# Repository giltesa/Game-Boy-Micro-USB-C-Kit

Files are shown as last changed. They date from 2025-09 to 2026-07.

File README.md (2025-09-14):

# Game Boy Micro: USB-C Kit

The <strong>Game Boy Micro: USB-C</strong> is a board that allows you to replace the original charging connector with a modern and standard <strong>USB-C</strong> port.

<strong>If your original connector is too old or damaged</strong> and you need a new one, or <strong>if you would like to charge your Game Boy Micro with a standard USB-C charger</strong>, like the charger for your <strong>Nintendo Switch</strong>, phone, or laptop, you can do so with this board.

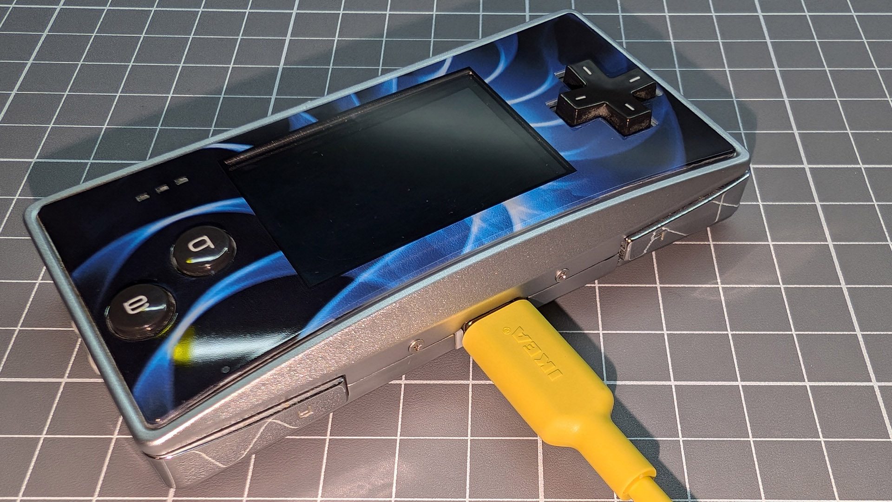
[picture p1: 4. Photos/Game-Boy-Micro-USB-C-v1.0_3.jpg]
GAME-BOY-MICRO-USB-C-Kit

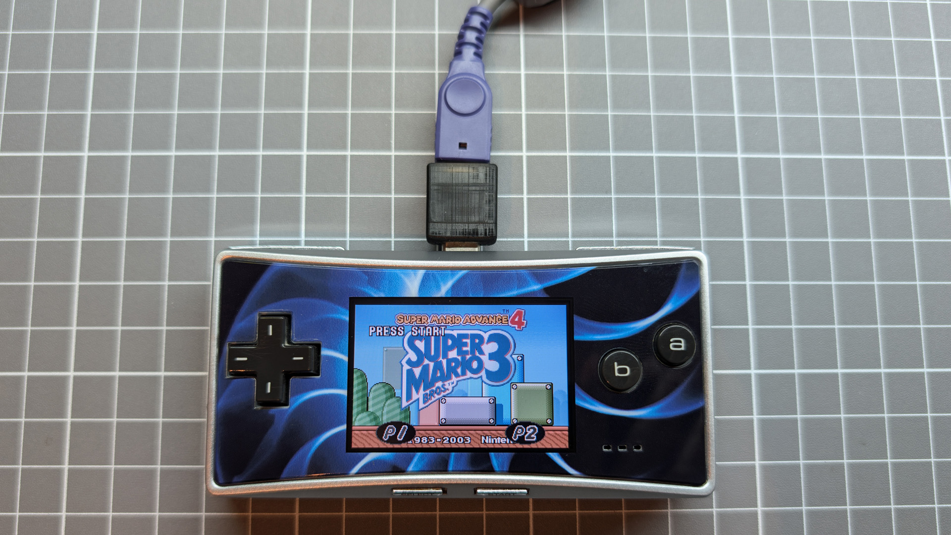
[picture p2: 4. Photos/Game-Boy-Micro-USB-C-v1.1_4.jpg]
GAME-BOY-MICRO-USB-C-Kit


## Would you like it?

[**Game Boy Micro: USB-C Kit**](https://shop.giltesa.com/product/game-boy-micro-usb-c-kit/)

## License

This project is licensed under a **Creative Commons** license:
**[Attribution-NonCommercial-ShareAlike 4.0 International (CC BY-NC-SA 4.0) ](https://creativecommons.org/licenses/by-nc-sa/4.0/)**

Check the [LICENSE.md](LICENSE.md) for more information.

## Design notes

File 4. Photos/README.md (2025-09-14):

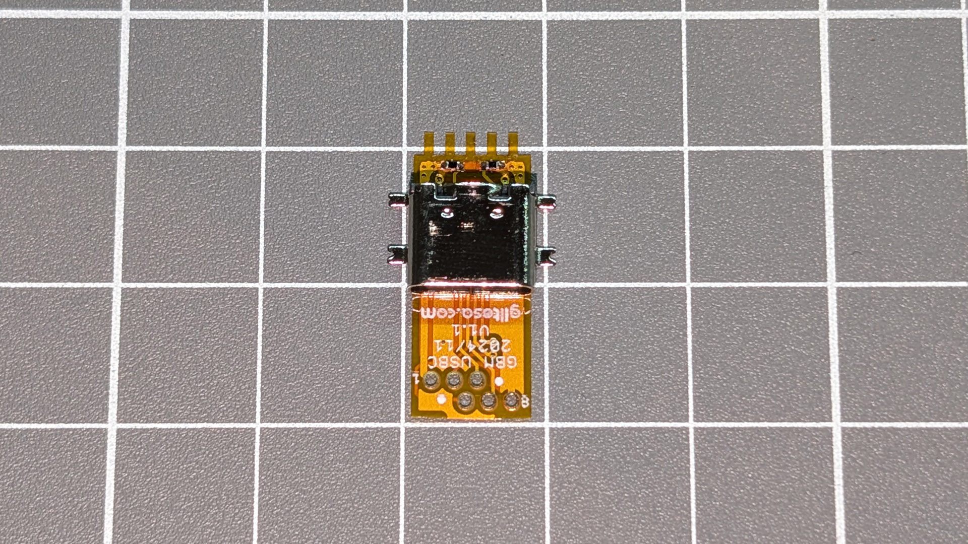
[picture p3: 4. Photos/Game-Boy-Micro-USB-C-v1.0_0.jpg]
GAME-BOY-MICRO-USB-C-Kit

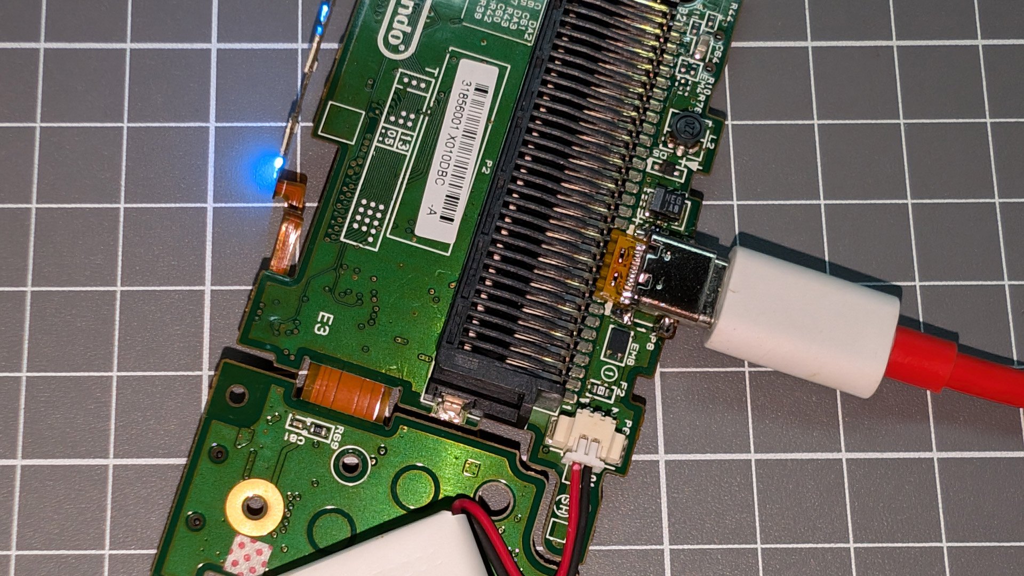
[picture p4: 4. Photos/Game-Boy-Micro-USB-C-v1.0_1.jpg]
GAME-BOY-MICRO-USB-C-Kit

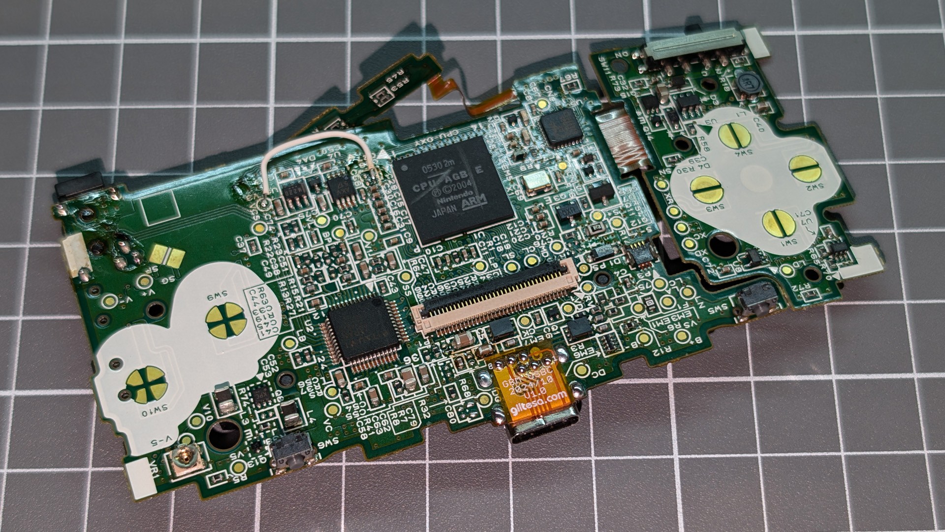
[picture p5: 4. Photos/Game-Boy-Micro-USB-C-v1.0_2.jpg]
GAME-BOY-MICRO-USB-C-Kit

GAME-BOY-MICRO-USB-C-Kit
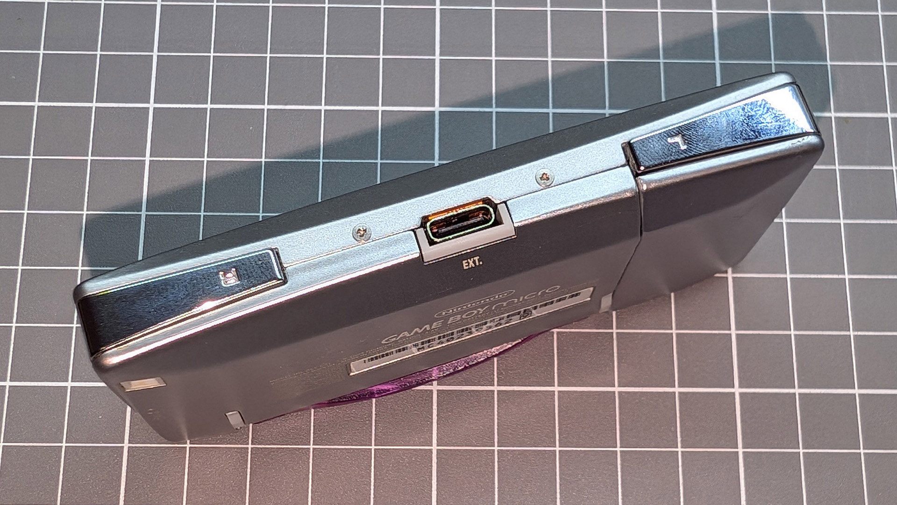
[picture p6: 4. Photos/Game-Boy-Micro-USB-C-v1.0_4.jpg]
GAME-BOY-MICRO-USB-C-Kit


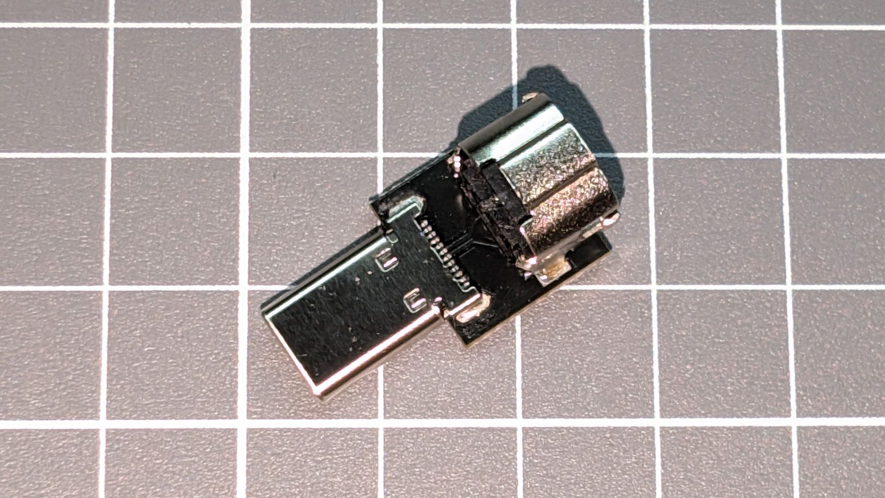
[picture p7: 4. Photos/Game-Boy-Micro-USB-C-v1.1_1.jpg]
GAME-BOY-MICRO-USB-C-Kit

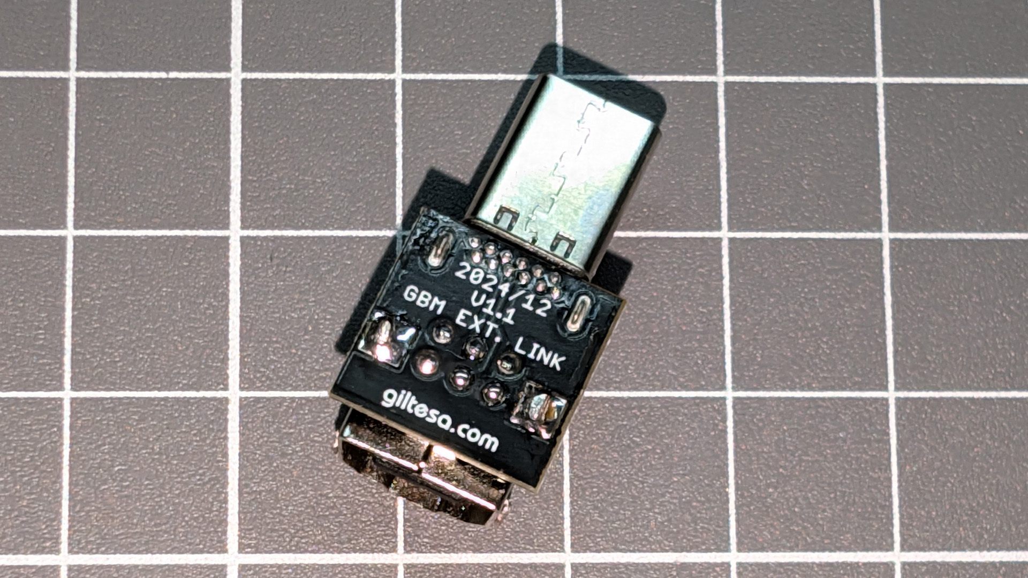
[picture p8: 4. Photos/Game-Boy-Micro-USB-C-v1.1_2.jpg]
GAME-BOY-MICRO-USB-C-Kit

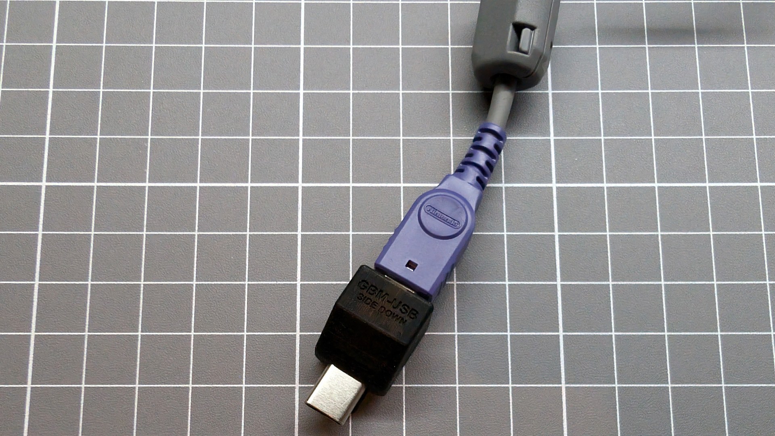
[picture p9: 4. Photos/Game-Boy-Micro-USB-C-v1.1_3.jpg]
GAME-BOY-MICRO-USB-C-Kit

GAME-BOY-MICRO-USB-C-Kit

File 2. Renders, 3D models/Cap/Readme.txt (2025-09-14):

The plastic cap is too weak and would have been a single color. In the end, I scrapped the idea, which is why it’s not included.

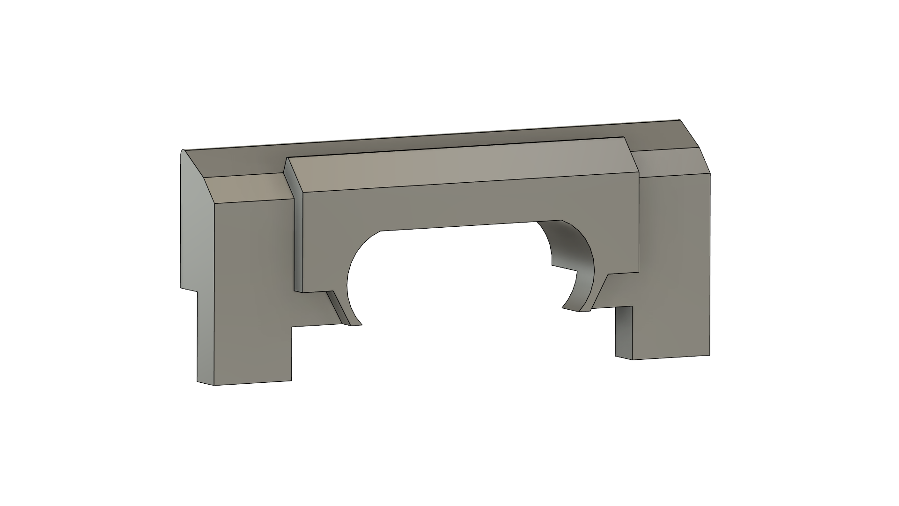
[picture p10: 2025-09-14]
2. Renders, 3D models/Cap/GBM v13.png

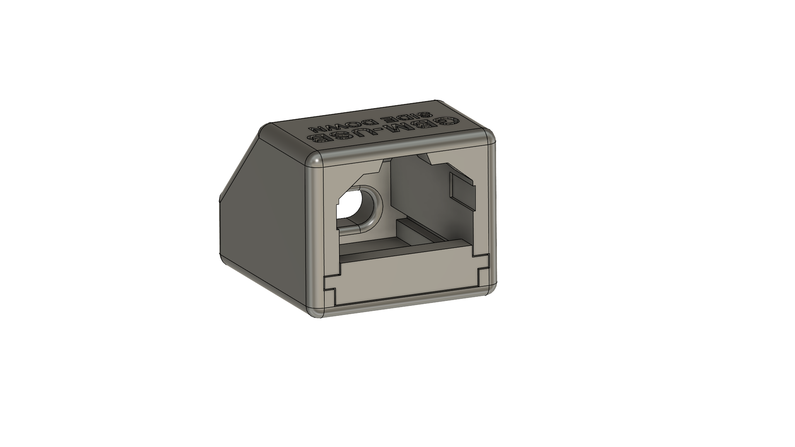
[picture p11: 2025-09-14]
2. Renders, 3D models/Adapter/GBM-ADAPTER_v33.png

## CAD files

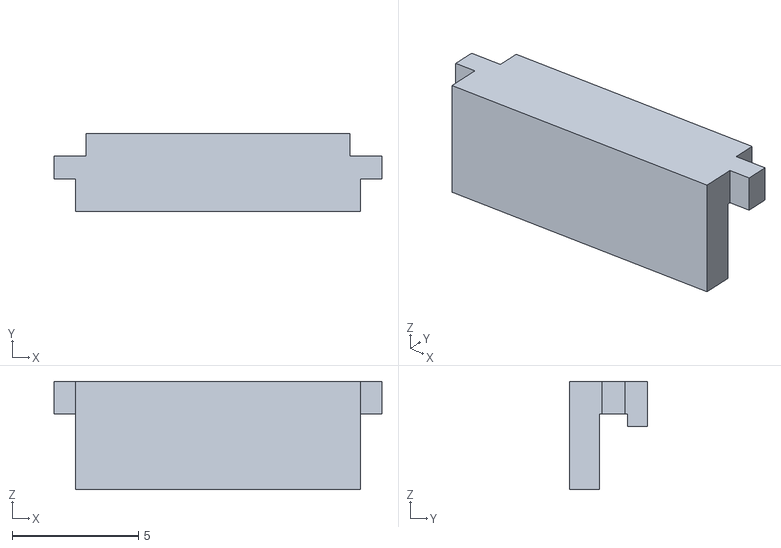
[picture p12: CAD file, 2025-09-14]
2. Renders, 3D models/Adapter/GBM-ADAPTER_LID_v33.stl
13.0 x 3.10 x 4.30

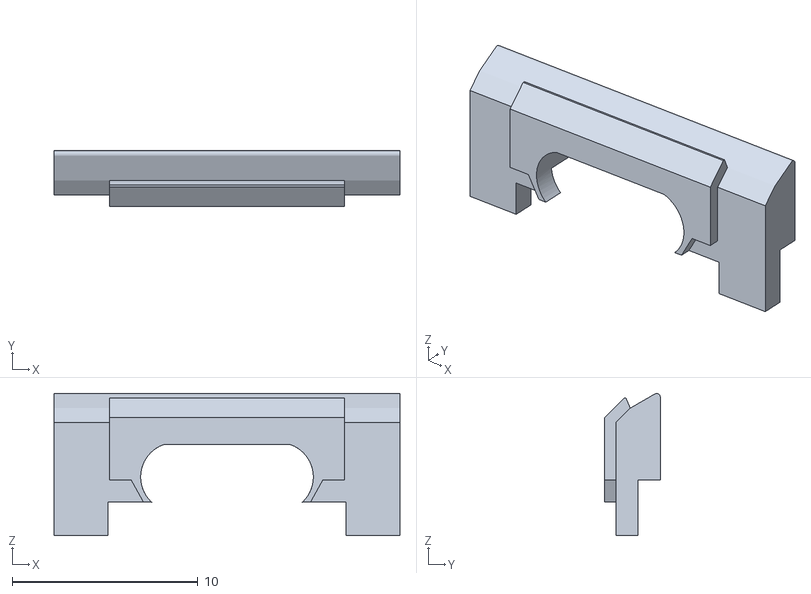
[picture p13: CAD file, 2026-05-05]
2. Renders, 3D models/Cap/GBM v13.stl
18.6 x 3.00 x 7.65

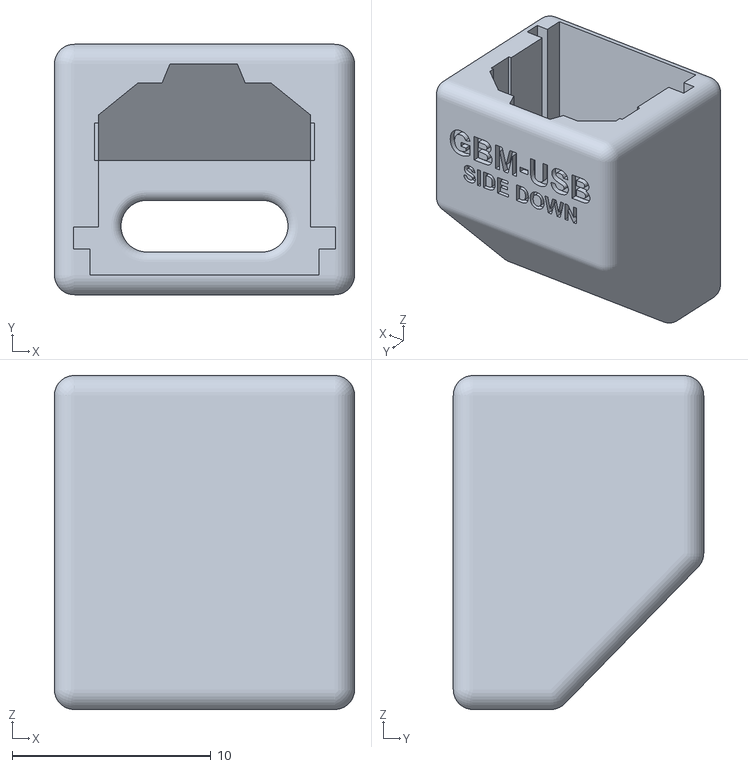
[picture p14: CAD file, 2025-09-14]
2. Renders, 3D models/Adapter/GBM-ADAPTER_v33.stl
15.1 x 12.6 x 16.8

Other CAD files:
2. Renders, 3D models/Adapter/GBM-ADAPTER_v33.f3d
2. Renders, 3D models/Cap/GBM v13.f3d
2. Renders, 3D models/PCB EXT LINK v1.0.skp
2. Renders, 3D models/PCB v1.0.skp

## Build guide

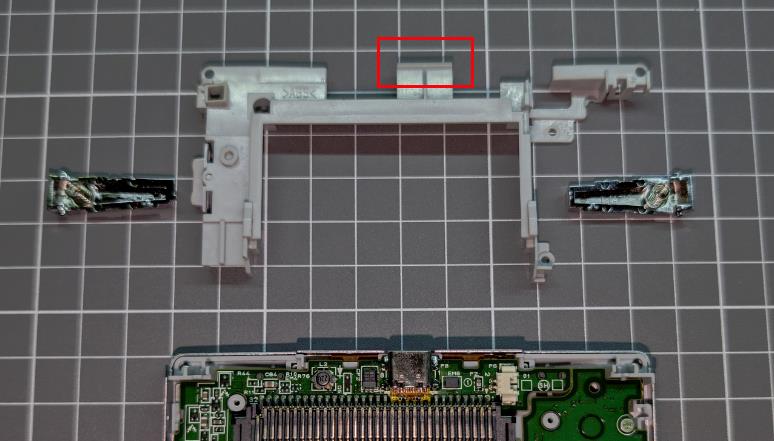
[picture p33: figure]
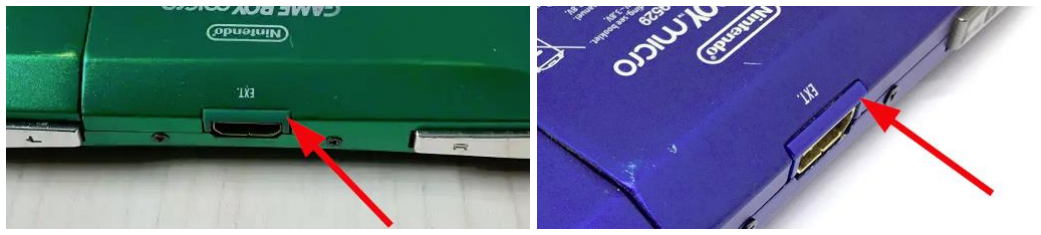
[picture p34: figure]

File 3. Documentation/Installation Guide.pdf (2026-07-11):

# USB-C KIT For

# Game Boy Micro

### PRODUCT

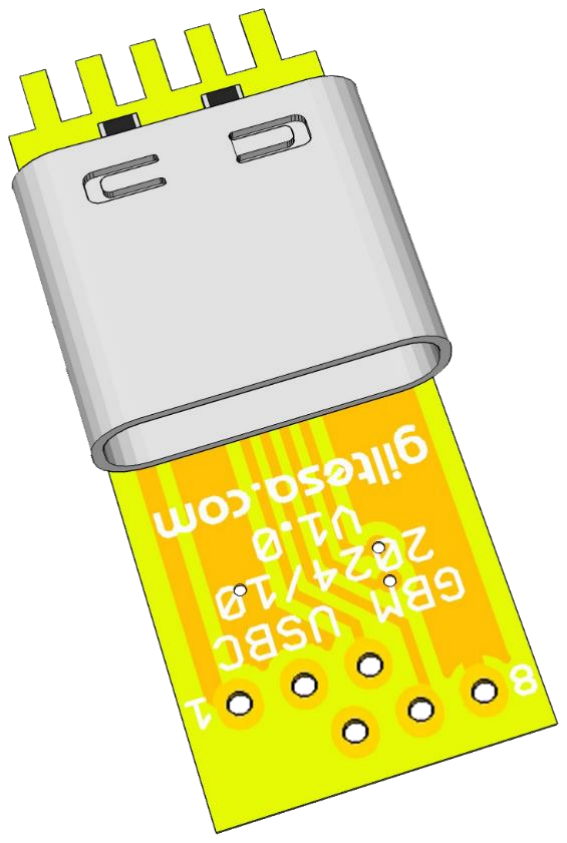
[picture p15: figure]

HTTPS://SHOP.GILTESA.COM/PRODUCT/GAME-BOY-MICRO-USB-C-KIT

# PLEASE READ THROUGH THESE INSTRUCTIONS

ENTIRELY BEFORE ATTEMPTING TO INSTALL.

# WARNING: IF YOU ARE NOT COMFORTABLE WITH SOLDERING, OR PERFORMING ANY STEP IN THIS

GUIDE, DO NOT PERFORM THE INSTALL YOURSELF.

# FIND SOMEONE WHO IS COMFORTABLE TO DO IT FOR

YOU.

INDEX

# Description

The Game Boy Micro: USB-C Kit is a board that allows to replace the original charging connector for a modern and standard USB-C.

If your original connector is too old or damaged and you need a new one, or if you would like to charge your Game Boy Micro with a standard USB-C charger, like the charger of your phone, laptop, you can with this kit.

# FEATURES

- Charging your Game Boy Micro with:
- USB power banks
- USB-A chargers
- USB-C chargers
- USB-C PD chargers (normal speed, not fast)
- USB-A to USB-C cables
- USB-C to USB-C cables
- Multiplayer connection support through an adapter.

# INCLUDED

- 1 flexible board.

# Recommended / REQUIRED (NOT INCLUDED)

- Tri-wing and Phillips screwdriver
- Kapton tape
- Soldering iron
- Tin
- Flux
- Desoldering pump
- Desoldering mesh
- Isopropyl alcohol

# Board details

This small flexible board has a total of 10 pads: 4 of them correspond to the USB-C pins/legs, and the others are for power and multiplayer connection.

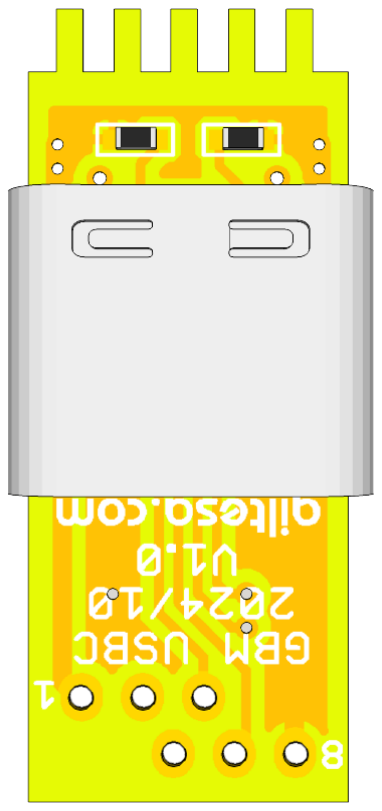
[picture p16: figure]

The pads are, from left to right in the image:

- VCC | The 5V line from the USB-C.
- SO | Serial output
- SI | Serial input
- SD | Serial data
- SC | Serial clock
- GND | The ground pad.
- USB SHIELD LEGS They secure the board firmly to the mainboard.

# Test the board!

Before starting the installation, you should test the board. If it doesn’t work contact me for a replacement (https://shop.giltesa.com/refund-policy/) (all boards are fully tested, but they may damage during the shipping, we try to package them as better as possible), if it works, go ahead with the installation.

Connect the power from your USB charger to the USB-C connector on the board. Then, with a multimeter in voltage measurement mode, check for a 5V reading. If that's the case, continue with the installation.

NOTE: Make sure you are making proper contact on the sides of the pads.

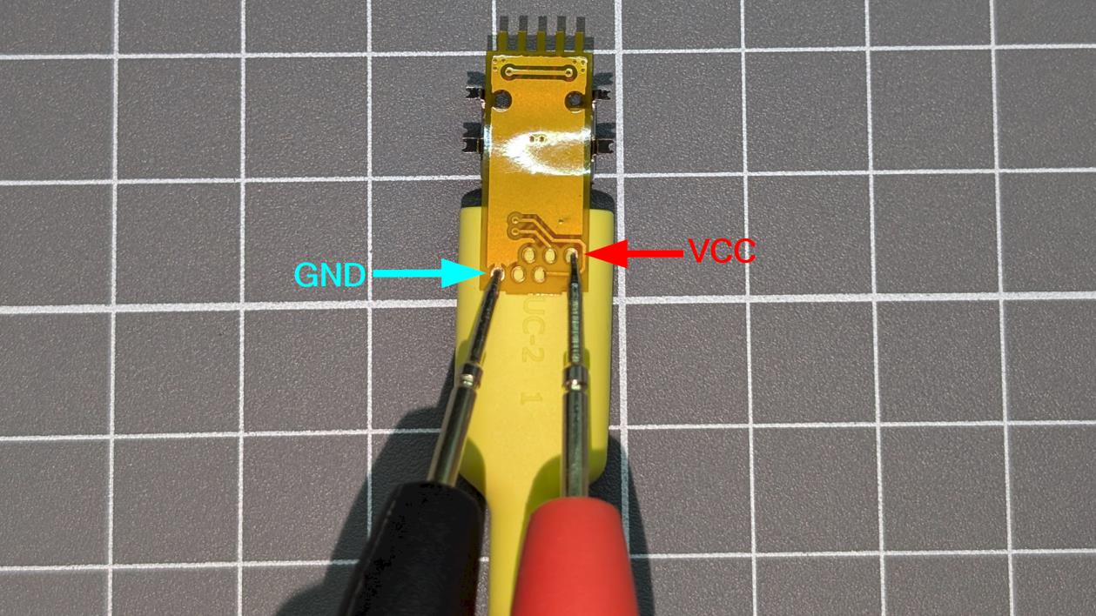
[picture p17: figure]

Unfortunately, it is not possible to test the data connection until the board is fully installed.

# INSTALLATION STEPS

Please, carefully read the following steps for a successful installation.

## Pre installation Steps

Before the installation, your Game Boy Micro may need some extra steps to have it ready for the kit.

1. Disassembly the Game Boy Micro

If the steps in this guide are insufficient and you can't proceed, you can refer to the iFixit guide (https://www.ifixit.com/Guide/Game+Boy+Micro+Motherboard+Replacement/2032) for opening the console.

This is the most delicate console ever made by Nintendo. When you open and handle it, do so with extreme care. The GBM mainboard consists of a rigid-flex main board and two secondary boards. These three boards are actually just one piece, so do not try to separate them or twist the connections between them.

First, remove the side screw holding the battery cover, and once done, disconnect the battery.

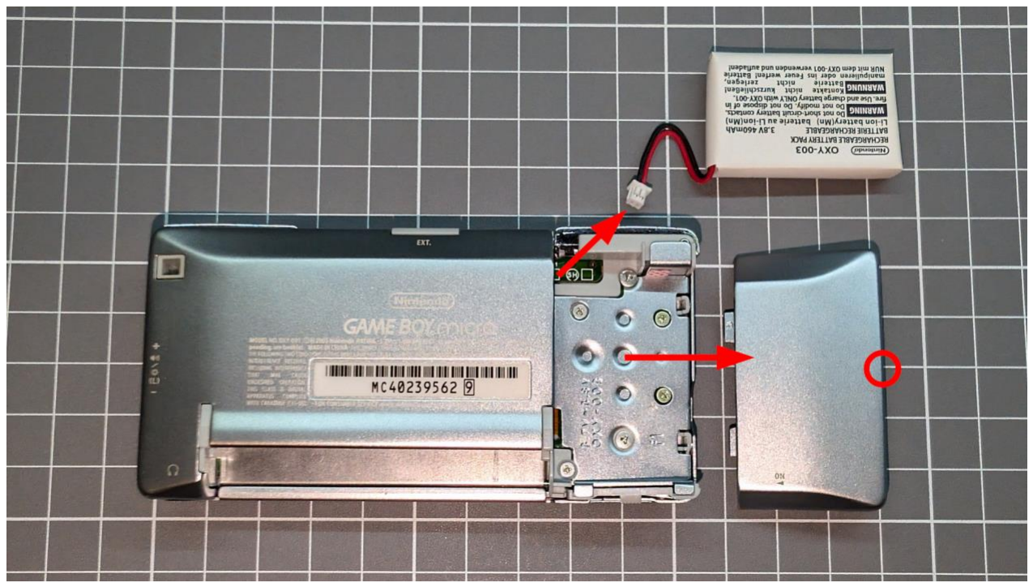
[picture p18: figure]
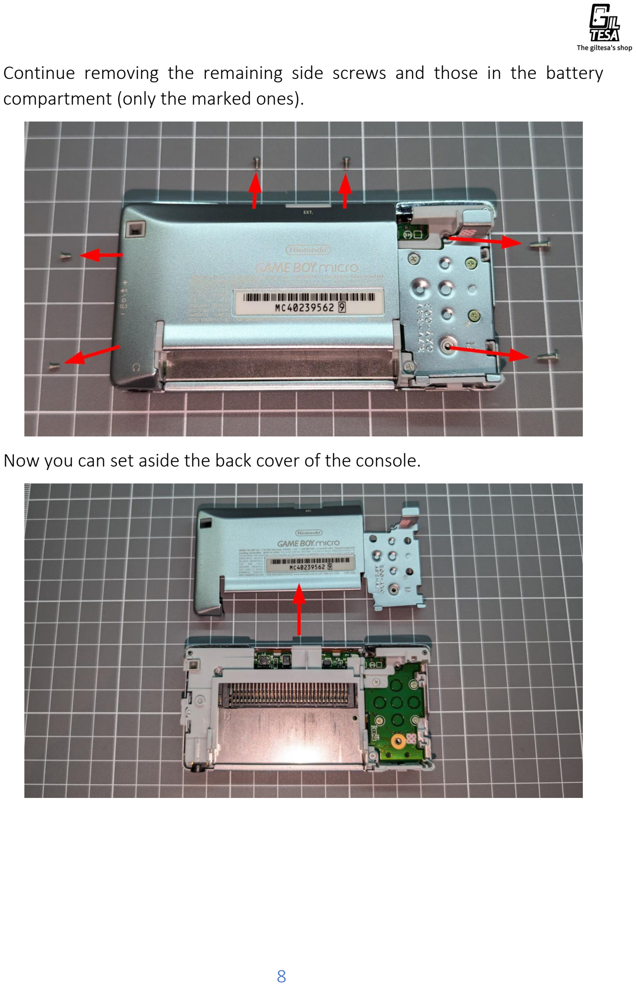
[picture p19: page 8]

Continue removing the remaining side screws and those in the battery compartment (only the marked ones).

Now you can set aside the back cover of the console.

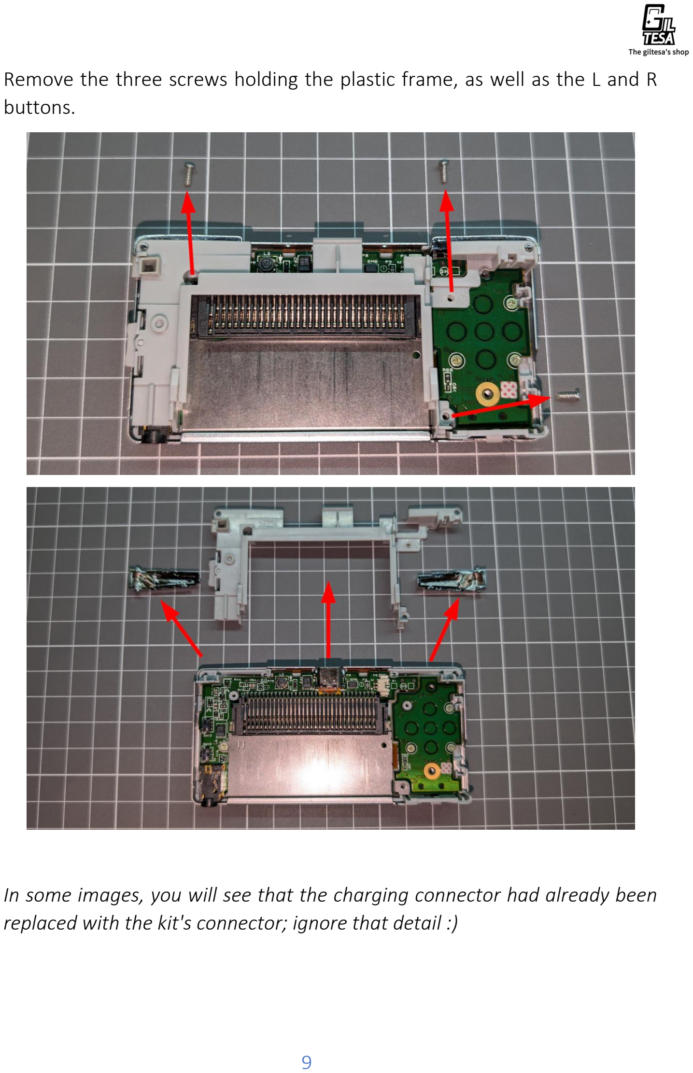
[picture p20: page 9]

Remove the three screws holding the plastic frame, as well as the L and R buttons.

In some images, you will see that the charging connector had already been replaced with the kit's connector; ignore that detail :)

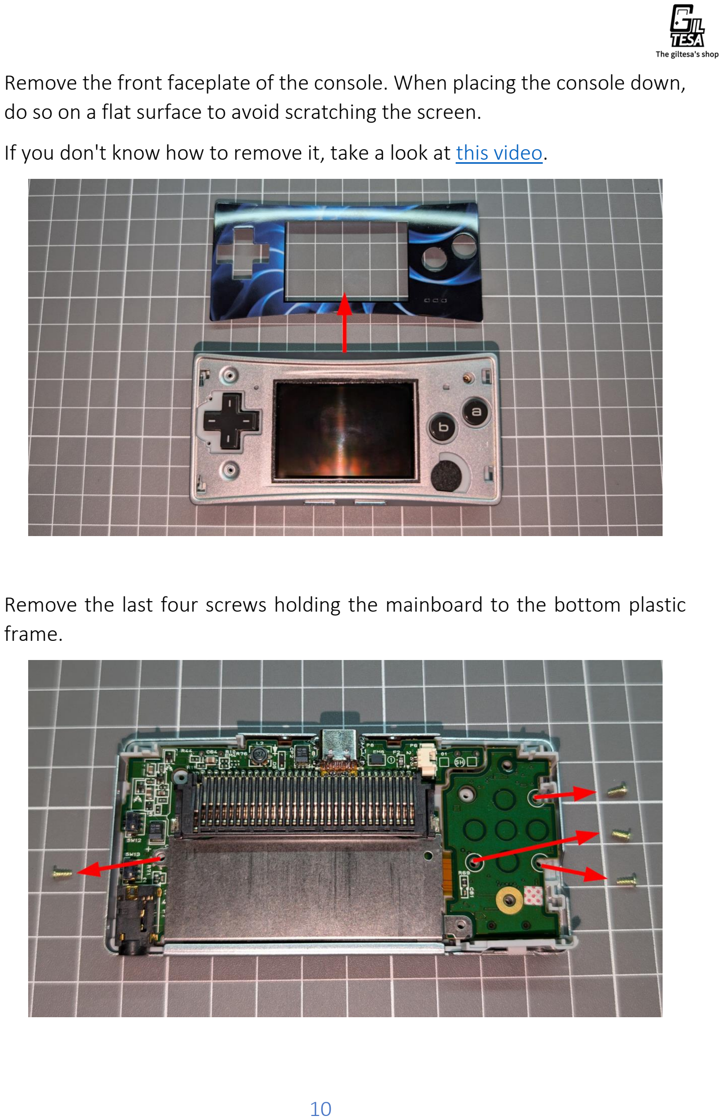
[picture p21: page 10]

Remove the front faceplate of the console. When placing the console down, do so on a flat surface to avoid scratching the screen.

If you don't know how to remove it, take a look at this video. (https://youtu.be/eAKtUo8MPlI)

Remove the last four screws holding the mainboard to the bottom plastic frame.

Now you can separate the mainboard from the front casing. To do this, use one hand to pinch the top of the mainboard and the screen at the same time. With your other hand, slowly move the casing in the opposite direction.

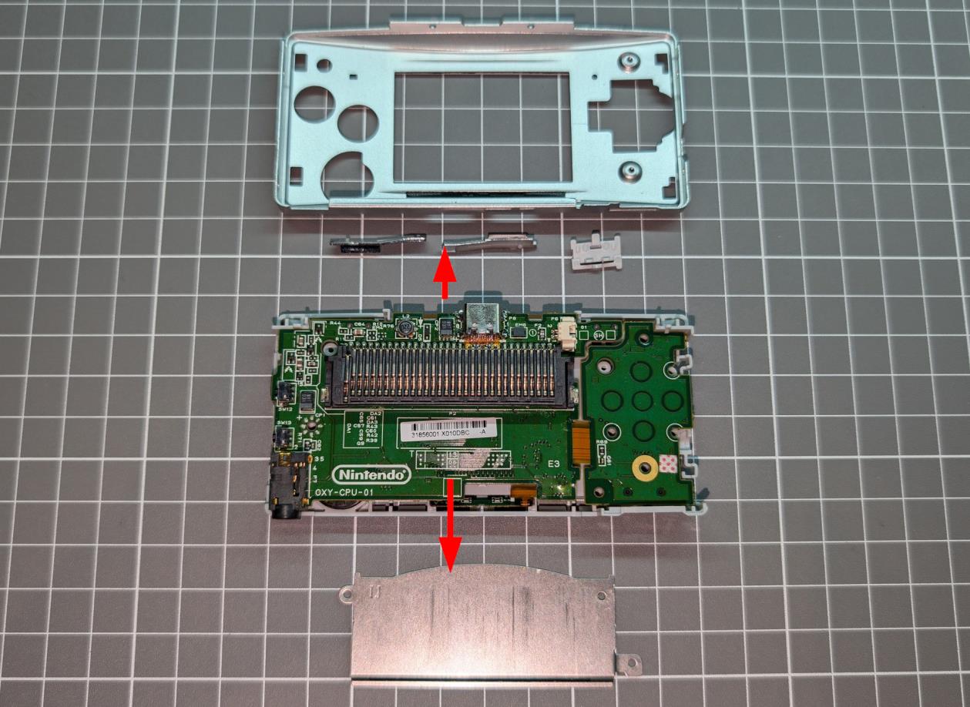
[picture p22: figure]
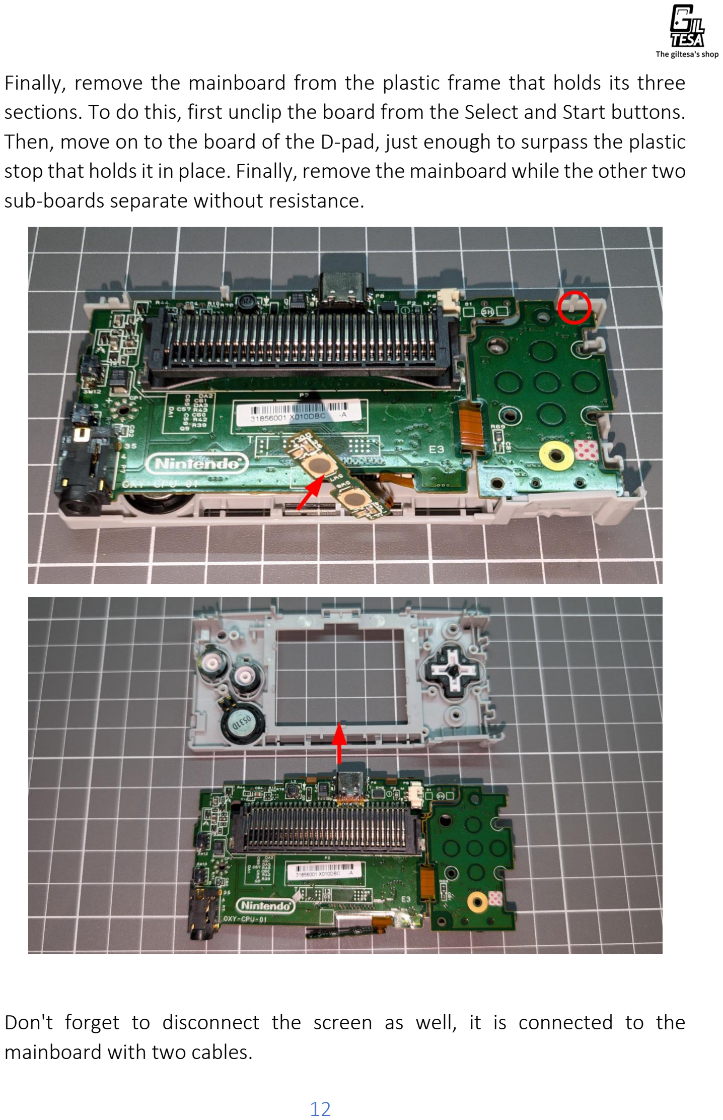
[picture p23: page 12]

Finally, remove the mainboard from the plastic frame that holds its three sections. To do this, first unclip the board from the Select and Start buttons. Then, move on to the board of the D-pad, just enough to surpass the plastic stop that holds it in place. Finally, remove the mainboard while the other two sub-boards separate without resistance.

Don't forget to disconnect the screen as well, it is connected to the mainboard with two cables.

## installation Steps

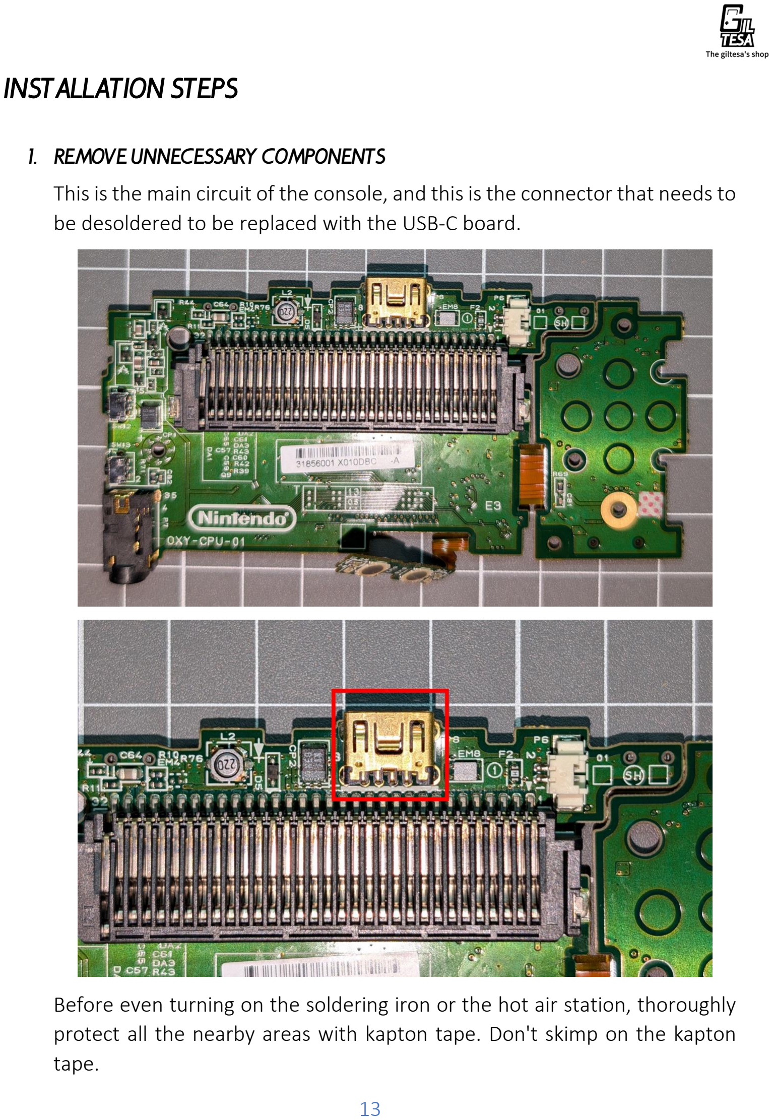
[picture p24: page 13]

1. Remove unnecessary components

This is the main circuit of the console, and this is the connector that needs to be desoldered to be replaced with the USB-C board.

Before even turning on the soldering iron or the hot air station, thoroughly protect all the nearby areas with kapton tape. Don't skimp on the kapton tape.

Now, remove the connector. This can be challenging because the twelve legs of the connector's housing are firmly attached to the mainboard.

Apply flux and desolder each leg one by one. You can also add higher-quality solder to mix with the existing solder, which will help you remove it all more easily.

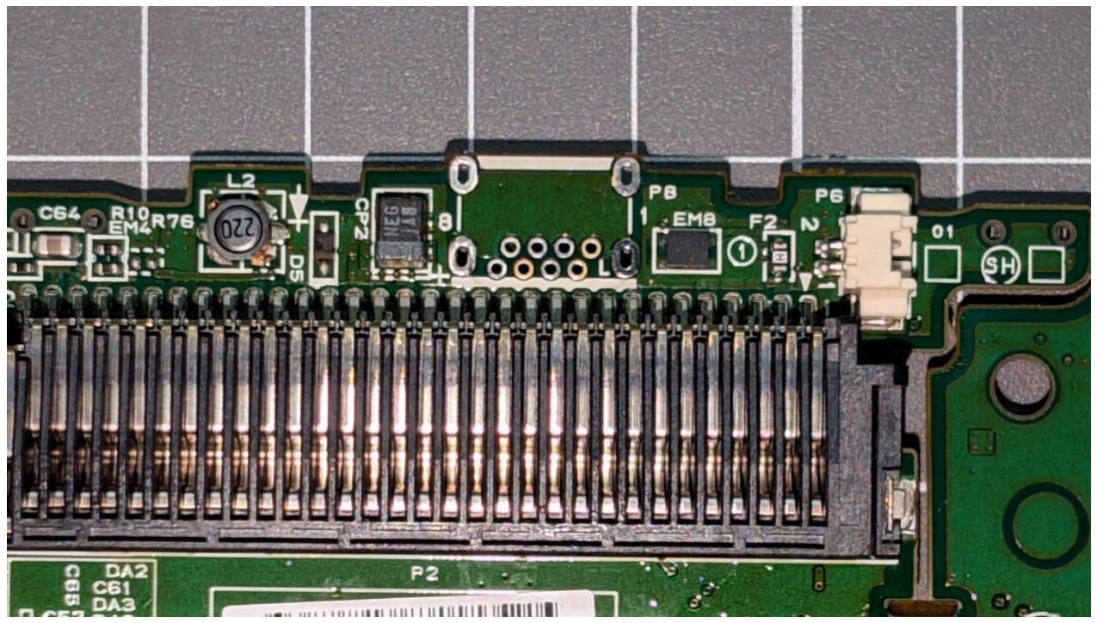
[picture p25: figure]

Remove the solder from the pins, ensuring they are not bridged together. It's not necessary to remove the solder from the four holes where the connector was soldered but try to ensure that the solder/pads are completely flat.

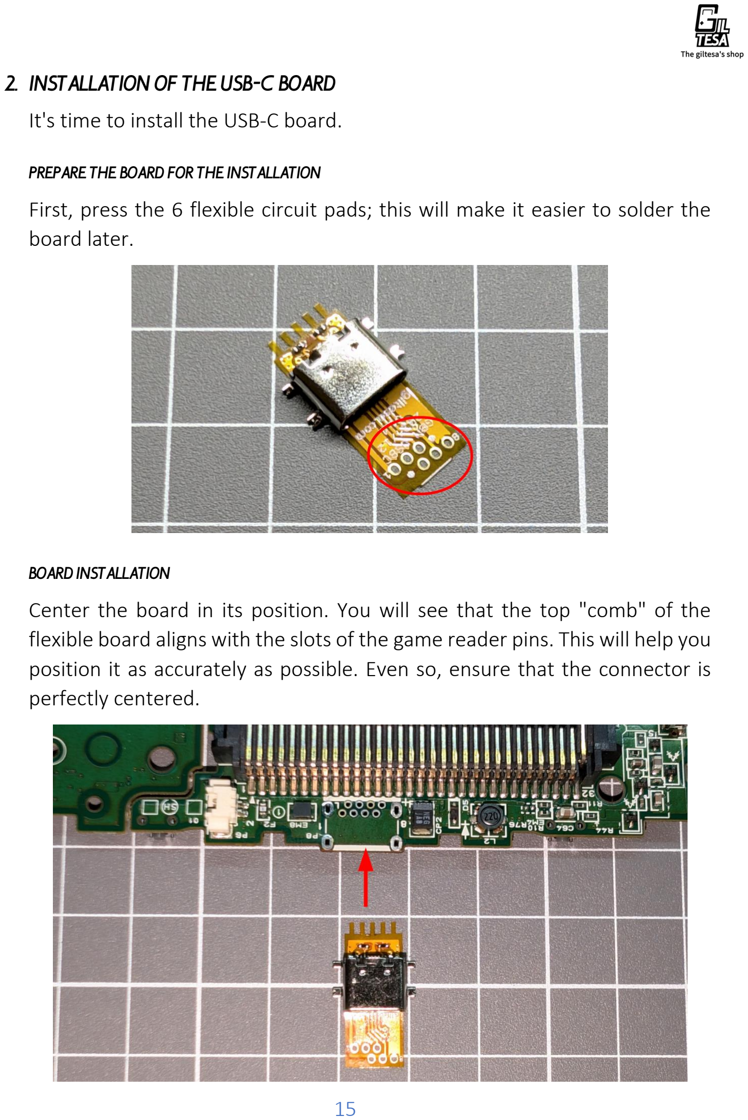
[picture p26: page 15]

2. Installation of the USB-C board

It's time to install the USB-C board.

PREPARE THE BOARD FOR THE INSTALLATION
First, press the 6 flexible circuit pads; this will make it easier to solder the board later.

BOARD INSTALLATION
Center the board in its position. You will see that the top "comb" of the flexible board aligns with the slots of the game reader pins. This will help you position it as accurately as possible. Even so, ensure that the connector is perfectly centered.

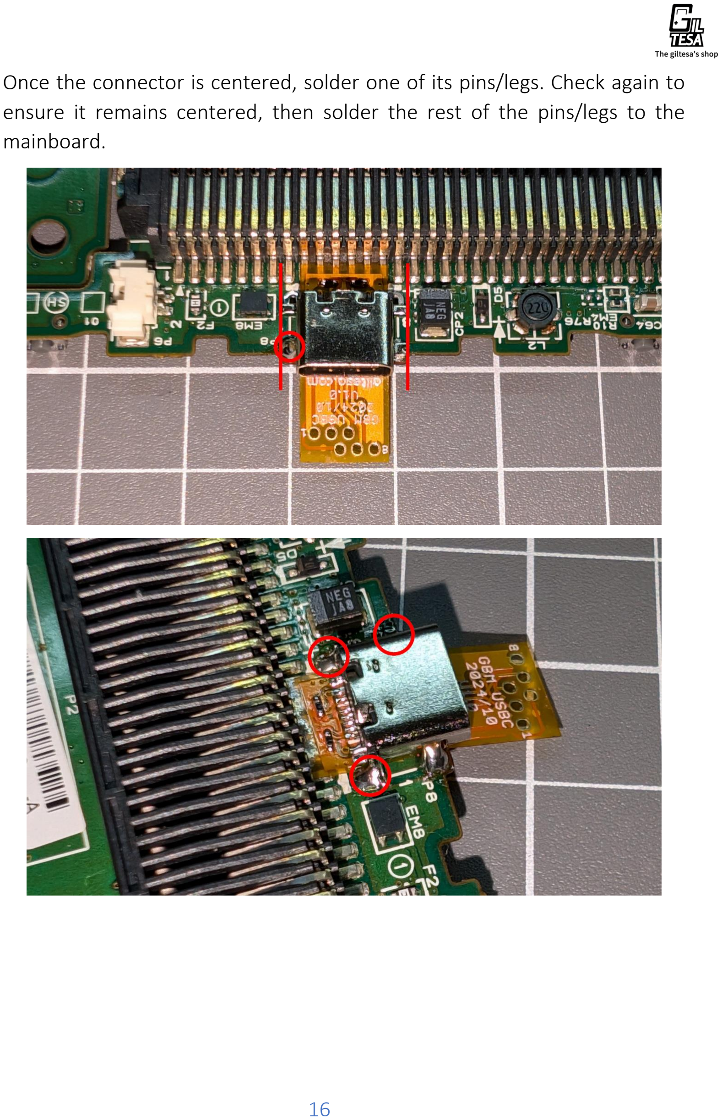
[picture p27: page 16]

Once the connector is centered, solder one of its pins/legs. Check again to ensure it remains centered, then solder the rest of the pins/legs to the mainboard.

Now, fold the flexible circuit over the GBM mainboard and align the pads/holes of the flexible board with the pads of the GBM.

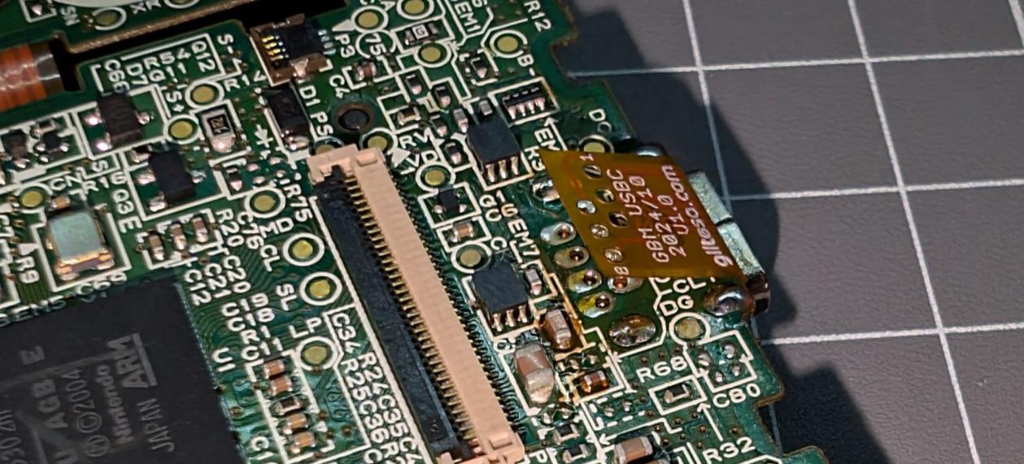
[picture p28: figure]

You can solder all 6 pads if you plan to use the multiplayer connection adapter. If that feature is not important to you, then it is sufficient to solder only the first pad on each side, that is, pad 1 and pad 8.

If you wish, before closing the console, you can connect the battery and the USB-C cable to the console to verify that it begins charging the battery.

To test the multiplayer connection, you will need to fully assemble the console.

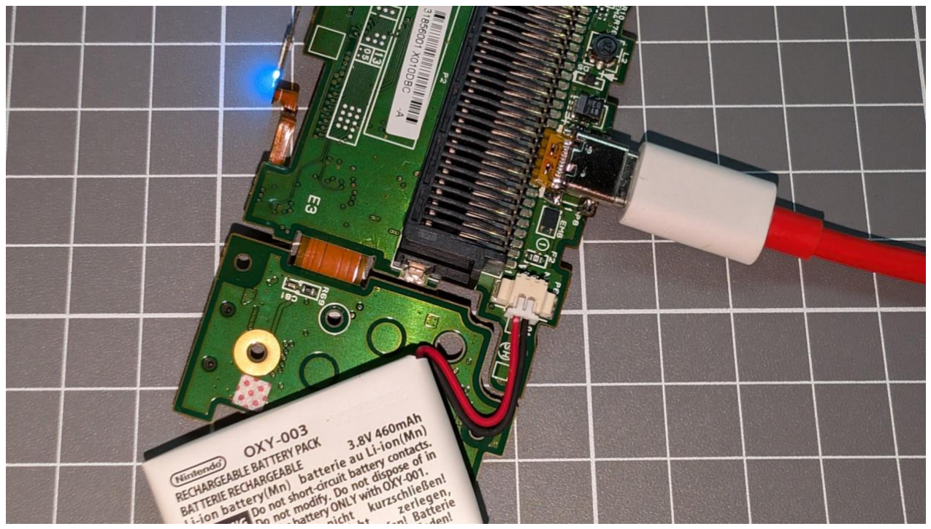
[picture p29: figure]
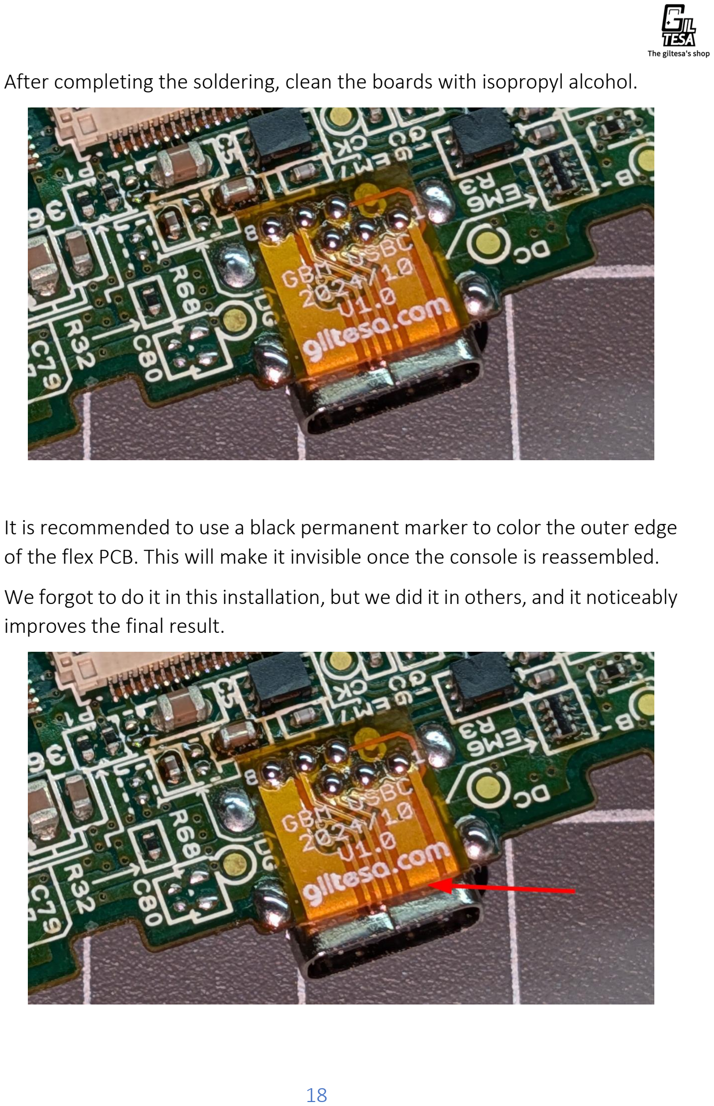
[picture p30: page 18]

After completing the soldering, clean the boards with isopropyl alcohol.

It is recommended to use a black permanent marker to color the outer edge of the flex PCB. This will make it invisible once the console is reassembled.

We forgot to do it in this installation, but we did it in others, and it noticeably improves the final result.

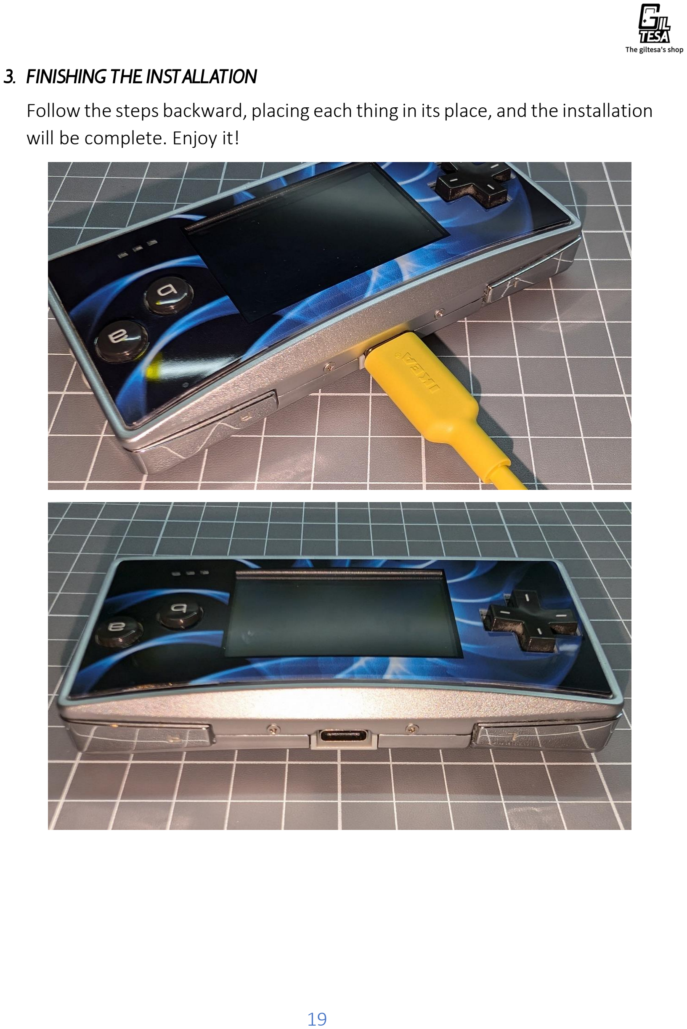
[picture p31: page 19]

3. Finishing the installation

Follow the steps backward, placing each thing in its place, and the installation will be complete. Enjoy it!

# Multiplayer Adapter

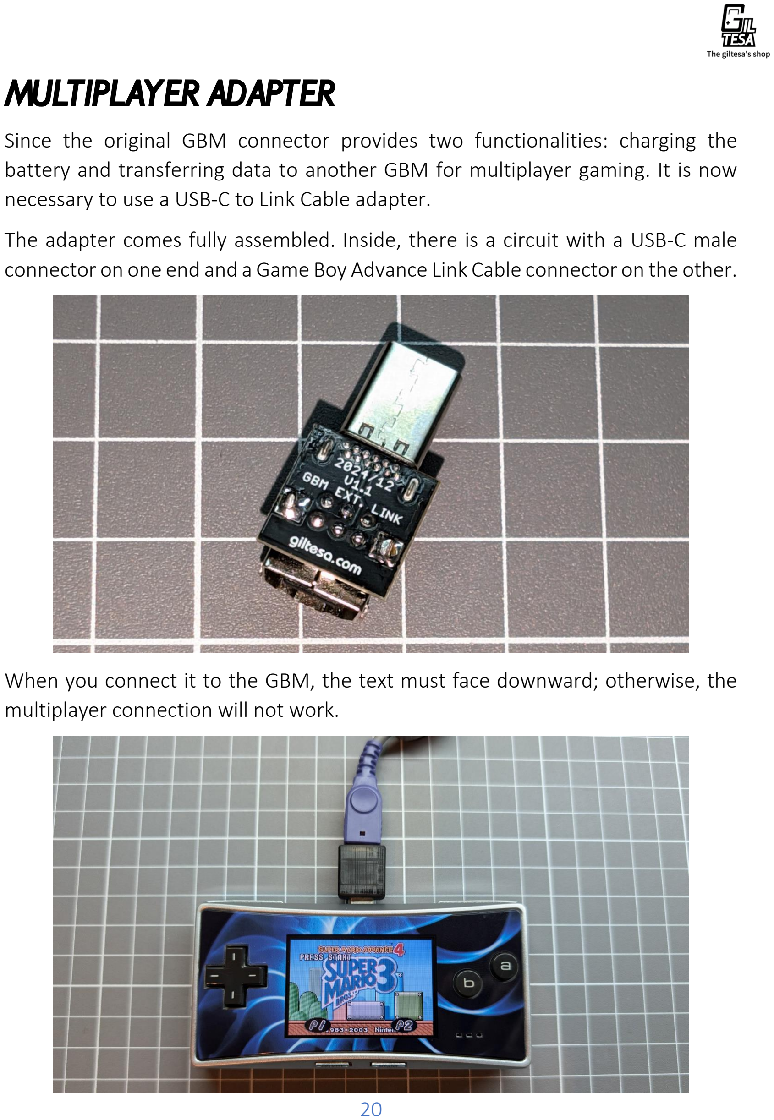
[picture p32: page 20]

Since the original GBM connector provides two functionalities: charging the battery and transferring data to another GBM for multiplayer gaming. It is now necessary to use a USB-C to Link Cable adapter.

The adapter comes fully assembled. Inside, there is a circuit with a USB-C male connector on one end and a Game Boy Advance Link Cable connector on the other.

When you connect it to the GBM, the text must face downward; otherwise, the multiplayer connection will not work.

# Frequently Asked Questions - FAQ

What charger can be used?
You can use any standard charger for mobile phones, computers, etc., with 5V 1A. It doesn't need to be a Power Delivery charger since this feature is not used. Of course, if you want to use a Power Delivery charger, there's no problem or risk.

Technical data for curious minds:

Power Delivery chargers can supply a wide range of voltages: 5V, 9V, 12V, 15V, and 20V. However, for this to happen, the device must communicate with the charger to explicitly request the desired voltage. Without this communication, the charger will never supply more than 5V. That's one of the advantages of USB-C, as it can be used with both old and modern devices.

My kit does not include a plastic cap to cover the hole.
The photos may make it look like there's a plastic cap installed, but that's not the case. It's actually the original plastic of the console. Depending on your console's color, the plastic will vary accordingly.
